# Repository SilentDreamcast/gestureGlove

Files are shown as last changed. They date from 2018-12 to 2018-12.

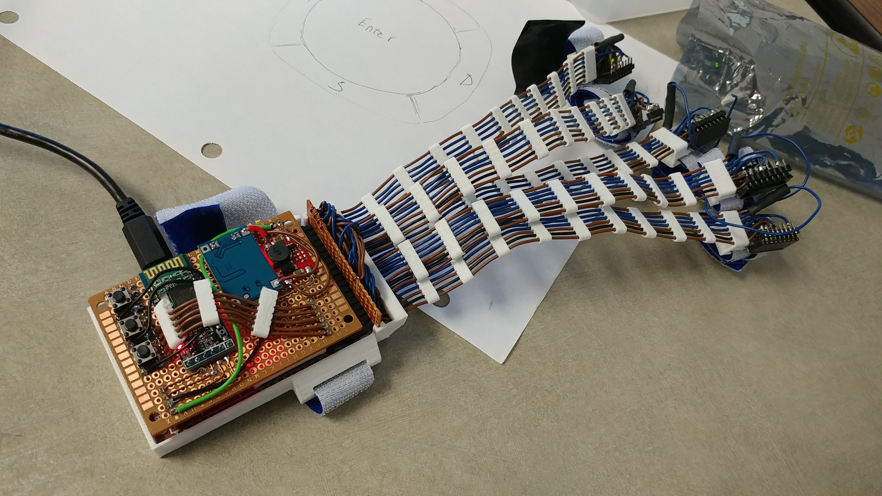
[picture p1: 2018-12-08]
glove.jpg

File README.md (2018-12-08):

# gestureGlove
gestureGlove is a wearable keyboard device that can recognize user hand gestures as a virtual keyboard. The core of the device is the Arduino Leonardo with an ATMEGA32u4 microcontroller.

## Getting Started

These instructions will help you recreate gestureGlove for testing and personal use.
There is a User Manual below.

### Prerequisites
* [Arduino IDE](https://www.arduino.cc/) - you don't have to use this but we did
* [Capacitive Sensing Library](https://playground.arduino.cc/Main/CapacitiveSensor?from=Main.CapSense) 
* [Keyboard Library](https://www.arduino.cc/reference/en/language/functions/usb/keyboard/)
* Arduino Leonardo - or any other board that uses the ATMEGA32u4 microcontroller or similar variant
* Soldering iron, some support components, etc.

### 3D printing
* We included the .stl files modeled in SketchUp to organize the many wires and provide a platform to attach a PCB to.
* These parts are attached to your hand with velcro straps.
* You do not need to print these parts but it makes quality of life and debugging better, especially with a ratsnest of wires and capacitive sensing wires.
* Please look at [glove.jpg] to see how it all comes together.

### Software Setup
```
1. Install the Arduino IDE (available for Windows, Linux, Mac)
2. Install the OLED library directly from within the IDE or git to your *Arduino/libraries* folder.
3. Download the DigiSafe source files
4. Open the .ino file
5. Modify the source to suit your hardware configuration.
6. Plug in your USB device, select the correct COM port and board.
7. Upload the code!
```
## User Manual
* Assemble your device by connecting the base module to the finger sensor array.
* By default the glove is configured for left-hand use. Right-hand use requires swapping the sensor indexes in the source code and reflashing the firmware to the Arduino. In the future, there will be a switch to swap handedness without reprogramming.
* Attach the base module to your wrist with velcro through the mounting points on the 3D printed parts.
* Attach each finger sensor by compressing the touch fabric between the velcro mounting points and finger. Depending on factors such as skin moisture, proximity to electrical noise, etc affects the reading of capacitive sensor. A custom touch threshold may need to be set in the source code and reflashed to the Arduino. In the future, capacitive autocalibration may be added, removing the need for reprogramming.
* After attaching to the hand, connect a USB cable to computer and keep your hand very still for a minute. This time is used for the calibration of the Accelerometer and Gyroscope sensors *notice how led transition time is slow*. Those LEDs represent what finger is currently being read.
* The device is ready for use, currently only supporting 3 buttons on 1 finger.
* Experiment with device...
* Debugging can be accessed by connecting via Bluetooth scannable as BTdebug. This is a serial port that outputs MPU6050 sensor values.
* DEBUGGING: on the base platform, there are 3 buttons.
* DEBUGGING: button 1: toggles debug state (sensor printouts or keyboard engine)
* DEBUGGING: button 2: switches between sensor type: RAW accelerometer, RAW gyroscope, Calibrated Gyroscope Angle with Accelerometer. (sensor printouts)
* DEBUGGING: button 3: switches between sensor axis type: X Y Z, X only, Y only, Z only. (sensor printouts)

## Authors

* **Marvin Mallari** - *Research, Base Hardware Designer, MPU i2c Multiplexer code*, repo-owner
* **Dawei Zhang** - *Research, Capacitive Hardware Designer, Hand Gesture detection code*
* **Kai He** - *Research, Hardware Research, Presentation*

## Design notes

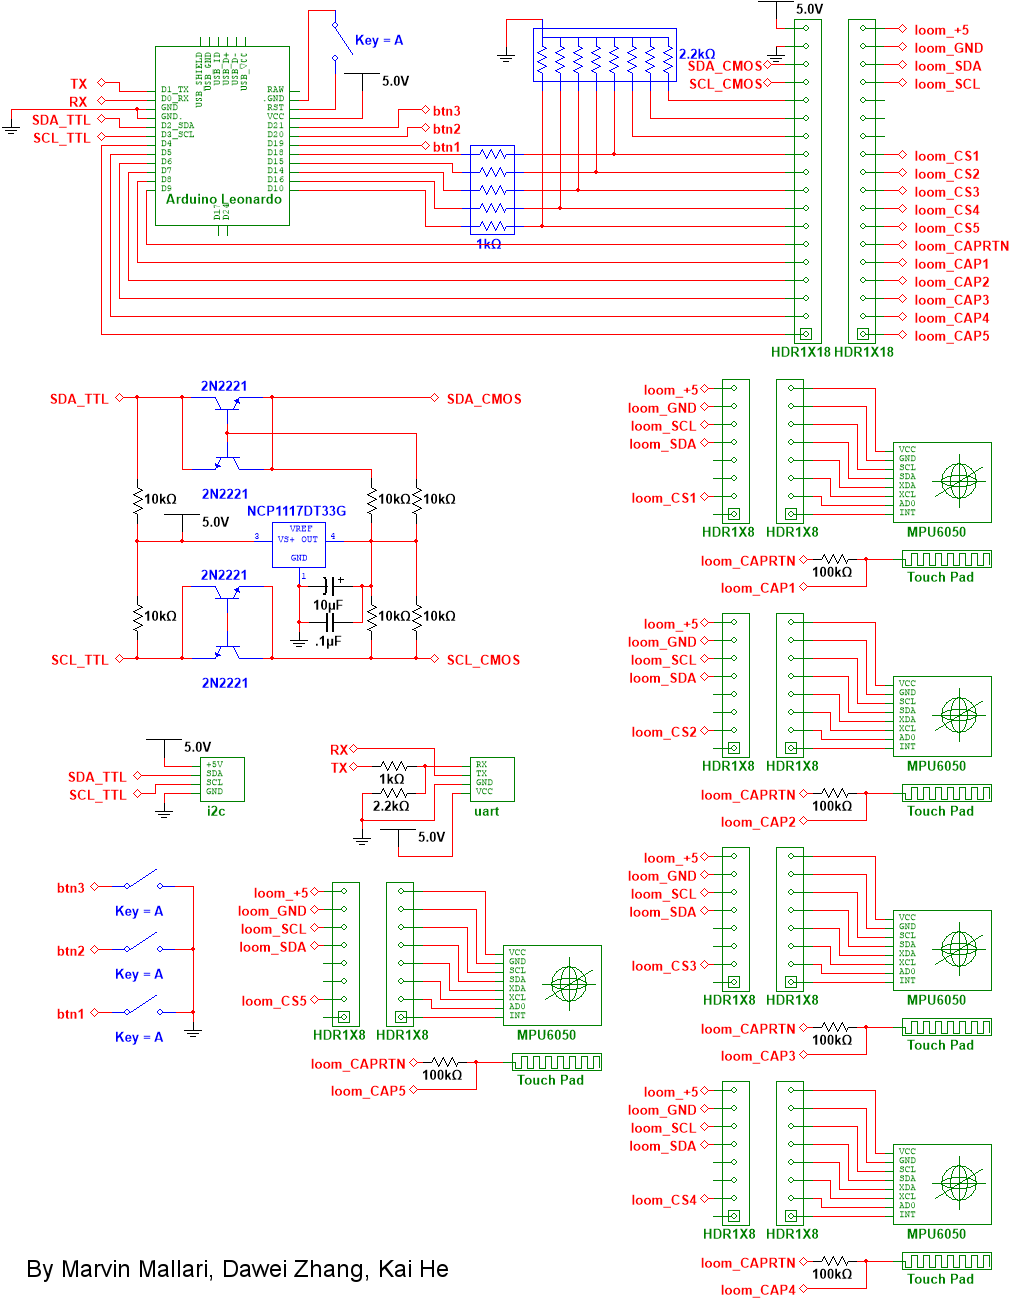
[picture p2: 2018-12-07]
schematic.png

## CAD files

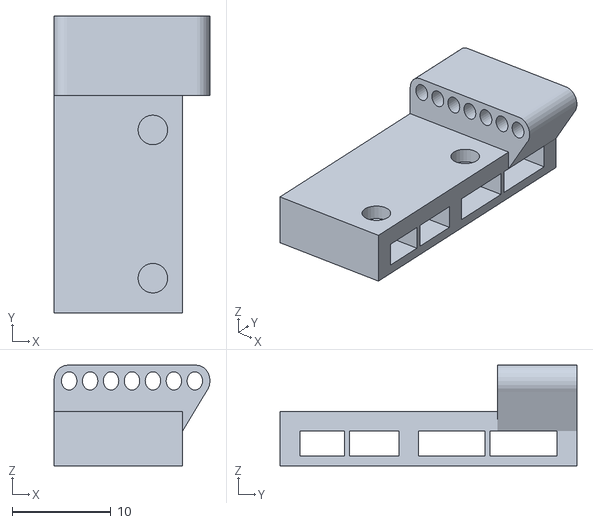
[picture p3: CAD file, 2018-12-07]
3D printable STL/MPU6050holder.stl
15.8 x 30.0 x 10.2

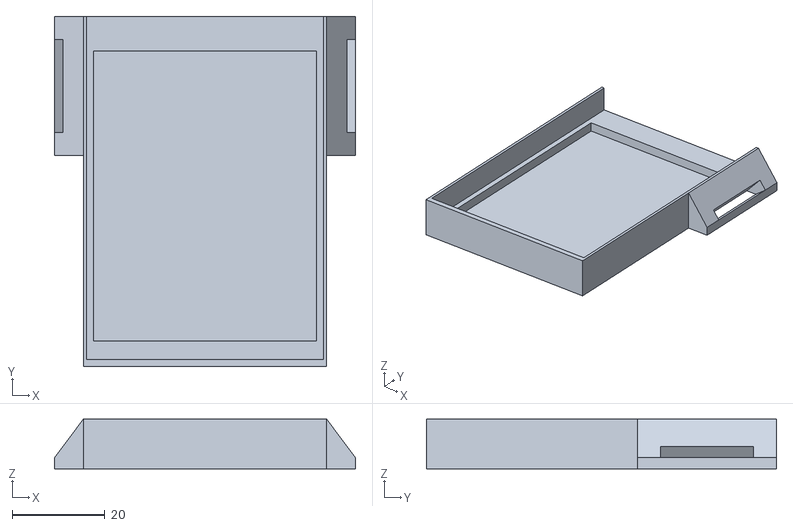
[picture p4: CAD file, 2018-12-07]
3D printable STL/baseHolder.stl
64.9 x 75.5 x 10.7

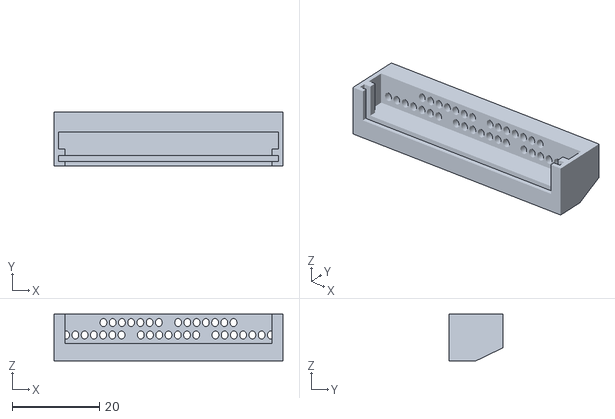
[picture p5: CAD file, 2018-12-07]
3D printable STL/headerComb.stl
52.5 x 12.4 x 10.7

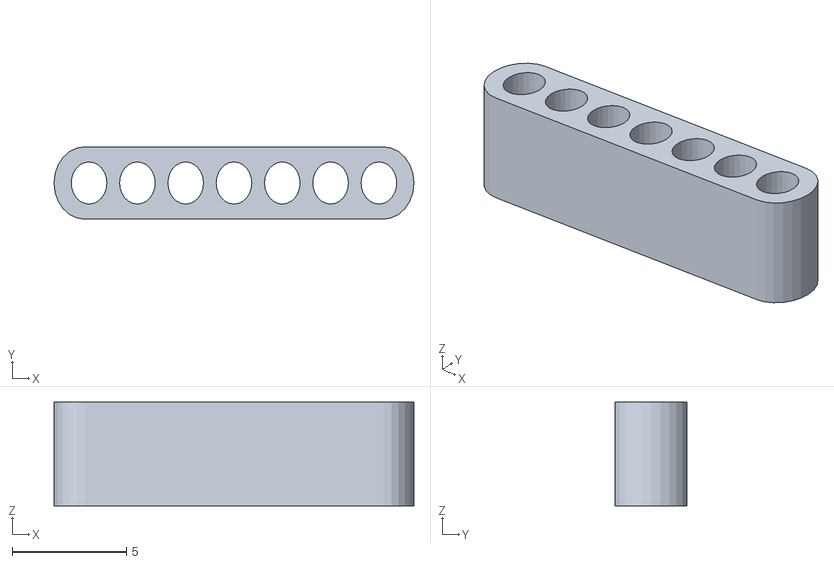
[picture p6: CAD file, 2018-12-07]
3D printable STL/1mmCableComb.stl
15.8 x 3.17 x 4.55

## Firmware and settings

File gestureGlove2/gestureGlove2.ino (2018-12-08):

////////////////////////////////////////////////////////////////////////////////
//                                  Authors                                   //
//----------------------------------------------------------------------------//
// Dawei Zhang                                                                //
// Marvin Anthony Mallari                                                     //
// Kai He                                                                     //
////////////////////////////////////////////////////////////////////////////////
//                                   Rules                                    //
//----------------------------------------------------------------------------//
// Provide github or author for any external libraries                        //
// Dynamic Memory (RAM) is small, use as little as possible                   //
//   -If possible use #define, const, byte, PROGMEM                           //
//   -Avoid int, float, long unless absolutely necessary                      //
// Fast code should not have any Serial.print or must be controllable         //
////////////////////////////////////////////////////////////////////////////////
//                                   Notes                                    //
//----------------------------------------------------------------------------//
// MPU6050 I2C address multiplexing schema: [WORKING 20 October 2018]         //
// * The MPU-6050 supports 2 I2C addresses, 0x68 & 0x69                       //
// * The GY-521 breakout board pulls AD0 low to set address to 0x68           //
// * This address manipulation schema works like Chip Select                  //
// * We will use pins defined in CSpin[] to pull AD0 lines LOW or HIGH        //
// ** Initially all CSpin[]s will be set HIGH 0x69                            //
// ** To read an individual sensor, a single CSpin will be set LOW 0x68       //
// ** Tockn's library will read the sensor based on default address 0x68      //
// ** After reading complete, said pin will be set HIGH 0x69                  //
// ** This repeats until all sensors are read.                                //
//                                                                            //
// MPU6050 drift, limitations, work around [WORK IN PROGRESS]                 //
// * USE DATATYPE ANGLE (calibrated with accelerometer)                       //
// * New schema based on vector guessing avoids sensor drift issue            //
//                                                                            //
// Capacitive Touch schema:                                                   //
// * using vector guessing to figure out position instead of trinonometry math//
// ** this method is good since it is less affected by sensor drift           //




#include "MPU6050_tockn_CUSTOM.h"
#include <Wire.h>
#include "Keyboard.h"
#include <CapacitiveSensor.h>

// define i2c address change pins using Arduino pins A0, D15, D14, D16, D10
const byte CSpin[] = {A0,15,14,16,10};

CapacitiveSensor cs_4_5 = CapacitiveSensor(4,5);
CapacitiveSensor cs_4_6 = CapacitiveSensor(4,6);
CapacitiveSensor cs_4_7 = CapacitiveSensor(4,7);
CapacitiveSensor cs_4_8 = CapacitiveSensor(4,8);
CapacitiveSensor cs_4_9 = CapacitiveSensor(4,9);

//define button pins
#define BTN1 A3
#define BTN2 A2
#define BTN3 A1

// xyz-axis for all fingers
float MPUX[] = {0,0,0,0,0};
float MPUY[] = {0,0,0,0,0};
float MPUZ[] = {0,0,0,0,0};

// xyz-axis as initial
float INITMPUX[] = {0,0,0,0,0};
float INITMPUY[] = {0,0,0,0,0};
float INITMPUZ[] = {0,0,0,0,0};

// initialize MPU6050 objects
MPU6050 MPU0(Wire);
MPU6050 MPU1(Wire);
MPU6050 MPU2(Wire);
MPU6050 MPU3(Wire);
MPU6050 MPU4(Wire);

#define KEY_BACKSPACE 178

// define keyboard 
char Keys[] =   {  KEY_BACKSPACE , 'w' , 's', 'a','d'};
boolean currentPressed[] = { false, false, false, false, false, false };

// Capactive touch threashhold, you might want to mess with this if you find its too
// sensitive or not sensitive enough
#define THRESH 6600

long total1 = 0.0;
long total2 = 0.0;
long total3 = 0.0;
long total4 = 0.0;
long total5 = 0.0;


void setup() {
  //delay(3000);
  Wire.begin(); //start I2C
  Serial1.begin(115200); // set baud-rate on ATMEGA 32u4 secondary UART port.
  // serial bluetooth module needs to be configured to 115200 baud with "AT+BAUD8" (115200), default "AT+BAUD4" (9600)
  cs_4_5.set_CS_AutocaL_Millis(0xFFFFFFFF); // turn off autocalibrate on channel 1 - just as an example for total1
  Serial.begin(115200);
  
  for(byte i = 0; i < 5; i++){
    pinMode(CSpin[i], OUTPUT);
    digitalWrite(CSpin[i], HIGH); // set all MPU6050 addresses to 0x69 by pulling AD0 HIGH, default 0x68 pulled LOW
  }

  pinMode(BTN1, INPUT_PULLUP);
  pinMode(BTN2, INPUT_PULLUP);
  pinMode(BTN3, INPUT_PULLUP);
  
  //i2cScan();
  
  digitalWrite(CSpin[0],LOW);
  delay(10);
  MPU0.begin();
  MPU0.calcGyroOffsets(true);
  digitalWrite(CSpin[0],HIGH);
  digitalWrite(CSpin[1],LOW);
  delay(10);
  MPU1.begin();
  MPU1.calcGyroOffsets(true);
  digitalWrite(CSpin[1],HIGH);
  digitalWrite(CSpin[2],LOW);
  delay(10);
  MPU2.begin();
  MPU2.calcGyroOffsets(true);
  digitalWrite(CSpin[2],HIGH);
  digitalWrite(CSpin[3],LOW);
  delay(10);
  MPU3.begin();
  MPU3.calcGyroOffsets(true);
  digitalWrite(CSpin[3],HIGH);
  digitalWrite(CSpin[4],LOW);
  delay(10);
  MPU4.begin();
  MPU4.calcGyroOffsets(true);
  digitalWrite(CSpin[4],HIGH);
}

boolean reduceMode = false;
byte rMtype = 0;
byte sType = 0;

void loop() {
  updateAll();
  //long start = millis();
  total1 =  cs_4_5.capacitiveSensor(30); // 30 SAMPLES
  total2 =  cs_4_6.capacitiveSensor(30);
  total3 =  cs_4_7.capacitiveSensor(30);
  total4 =  cs_4_8.capacitiveSensor(30);
  total5 =  cs_4_9.capacitiveSensor(30);
  
  if(digitalRead(BTN1) == LOW){ //turn on verbose mode
    delay(250);
    reduceMode = !reduceMode; //toggle
    Serial1.print("DEV MODE: ");
    Serial1.println(reduceMode);
  }
  if(digitalRead(BTN2) == LOW){ //change sensor type
    delay(250);
    sType++;
    if(sType > 4){
      sType = 0;
    }
  }
  if(digitalRead(BTN3) == LOW){ //change axis
    delay(250);
    rMtype++;
    if(rMtype > 3){
      rMtype = 0;
    }
  }
  if(reduceMode){
    if(sType == 0){
      Serial1.print("DATA TYPE: GYRO: ");
      updateGyro();
    }
    if(sType == 1){
      Serial1.print("DATA TYPE: GYRO ANGLE: ");
      updateGyroAngle();
    }
    if(sType == 2){
      Serial1.print("DATA TYPE: ANGLE: ");
      updateAngle();
    }
    if(sType == 3){
      Serial1.print("DATA TYPE: ACCELEROMETER: ");
      updateAccel();
    }
    if(sType == 4){
      Serial1.print("DATA TYPE: TOUCH: ");
      Serial1.print(total1);                  // print sensor output 1
      Serial1.print("\t");
      Serial1.print(total2);                  // print sensor output 2
      Serial1.print("\t");
      Serial1.print(total3);                // print sensor output 3
      Serial1.print("\t");
      Serial1.print(total4);                // print sensor output 3
      Serial1.print("\t");
      Serial1.println(total5);                // print sensor output 3
    }
    
    if(rMtype == 0 && sType != 4) {
      printX();
      printY();
      printZ();
      Serial1.println(); 
    }
    
    else if(rMtype == 1 && sType != 4) {
      printX();
      Serial1.println();
    }
    
    else if(rMtype == 2 && sType != 4) {
      printY();
      Serial1.println();
    }
    
    else if(rMtype == 3 && sType != 4) {
      printZ();
      Serial1.println();
    }
  }
  else{
    keyboardEngine();
  }

  //RUN SHORT RECALIBRATION
  if(digitalRead(BTN1) == LOW && digitalRead(BTN3) == LOW){
    digitalWrite(CSpin[0],LOW);
    delay(10);
    MPU0.quickCalcOffset(true);
    digitalWrite(CSpin[0],HIGH);
    digitalWrite(CSpin[1],LOW);
    delay(10);
    MPU1.quickCalcOffset(true);
    digitalWrite(CSpin[1],HIGH);
    digitalWrite(CSpin[2],LOW);
    delay(10);
    MPU2.quickCalcOffset(true);
    digitalWrite(CSpin[2],HIGH);
    digitalWrite(CSpin[3],LOW);
    delay(10);
    MPU3.quickCalcOffset(true);
    digitalWrite(CSpin[3],HIGH);
    digitalWrite(CSpin[4],LOW);
    delay(10);
    MPU4.quickCalcOffset(true);
    digitalWrite(CSpin[4],HIGH);
  }
}

void printX(){
  Serial1.print("X: ");
  for(byte i = 0; i < 5; i++){
    Serial1.print(MPUX[i]);
    Serial1.print(", ");
  }
}

void printY(){
  Serial1.print("Y: ");
  for(byte i = 0; i < 5; i++){
    Serial1.print(MPUY[i]);
    Serial1.print(", ");
  }
}

void printZ(){
  Serial1.print("Z: ");
  for(byte i = 0; i < 5; i++){
    Serial1.print(MPUZ[i]);
    Serial1.print(", ");
  }
}

// READ ALL SENSORS AND STORE THEM IN THEIR OWN OBJECT MEMORY
void updateAll(){
  digitalWrite(CSpin[0],LOW);
  delay(10);
  MPU0.update();
  digitalWrite(CSpin[0],HIGH);
  delay(10);
  digitalWrite(CSpin[1],LOW);
  delay(10);
  MPU1.update();
  digitalWrite(CSpin[1],HIGH);
  delay(10);
  digitalWrite(CSpin[2],LOW);
  delay(10);
  MPU2.update();
  digitalWrite(CSpin[2],HIGH);
  delay(10);
  digitalWrite(CSpin[3],LOW);
  delay(10);
  MPU3.update();
  digitalWrite(CSpin[3],HIGH);
  delay(10);
  digitalWrite(CSpin[4],LOW);
  delay(10);
  MPU4.update();
  digitalWrite(CSpin[4],HIGH);
}

void updateGyro(){
  MPUX[0] = MPU0.getGyroX();
  MPUX[1] = MPU1.getGyroX();
  MPUX[2] = MPU2.getGyroX();
  MPUX[3] = MPU3.getGyroX();
  MPUX[4] = MPU4.getGyroX();
  
  MPUY[0] = MPU0.getGyroY();
  MPUY[1] = MPU1.getGyroY();
  MPUY[2] = MPU2.getGyroY();
  MPUY[3] = MPU3.getGyroY();
  MPUY[4] = MPU4.getGyroY();
  
  MPUZ[0] = MPU0.getGyroZ();
  MPUZ[1] = MPU1.getGyroZ();
  MPUZ[2] = MPU2.getGyroZ();
  MPUZ[3] = MPU3.getGyroZ();
  MPUZ[4] = MPU4.getGyroZ();
}

void updateGyroAngle(){
  MPUX[0] = MPU0.getGyroAngleX();
  MPUX[1] = MPU1.getGyroAngleX();
  MPUX[2] = MPU2.getGyroAngleX();
  MPUX[3] = MPU3.getGyroAngleX();
  MPUX[4] = MPU4.getGyroAngleX();
  
  MPUY[0] = MPU0.getGyroAngleY();
  MPUY[1] = MPU1.getGyroAngleY();
  MPUY[2] = MPU2.getGyroAngleY();
  MPUY[3] = MPU3.getGyroAngleY();
  MPUY[4] = MPU4.getGyroAngleY();
  
  MPUZ[0] = MPU0.getGyroAngleZ();
  MPUZ[1] = MPU1.getGyroAngleZ();
  MPUZ[2] = MPU2.getGyroAngleZ();
  MPUZ[3] = MPU3.getGyroAngleZ();
  MPUZ[4] = MPU4.getGyroAngleZ();
}

void updateAngle(){
  MPUX[0] = MPU0.getAngleX();
  MPUX[1] = MPU1.getAngleX();
  MPUX[2] = MPU2.getAngleX();
  MPUX[3] = MPU3.getAngleX();
  MPUX[4] = MPU4.getAngleX();
  
  MPUY[0] = MPU0.getAngleY();
  MPUY[1] = MPU1.getAngleY();
  MPUY[2] = MPU2.getAngleY();
  MPUY[3] = MPU3.getAngleY();
  MPUY[4] = MPU4.getAngleY();
  
  MPUZ[0] = MPU0.getAngleZ();
  MPUZ[1] = MPU1.getAngleZ();
  MPUZ[2] = MPU2.getAngleZ();
  MPUZ[3] = MPU3.getAngleZ();
  MPUZ[4] = MPU4.getAngleZ();
}

void updateAccel(){
  MPUX[0] = MPU0.getAccX();
  MPUX[1] = MPU1.getAccX();
  MPUX[2] = MPU2.getAccX();
  MPUX[3] = MPU3.getAccX();
  MPUX[4] = MPU4.getAccX();
  
  MPUY[0] = MPU0.getAccY();
  MPUY[1] = MPU1.getAccY();
  MPUY[2] = MPU2.getAccY();
  MPUY[3] = MPU3.getAccY();
  MPUY[4] = MPU4.getAccY();
  
  MPUZ[0] = MPU0.getAccZ();
  MPUZ[1] = MPU1.getAccZ();
  MPUZ[2] = MPU2.getAccZ();
  MPUZ[3] = MPU3.getAccZ();
  MPUZ[4] = MPU4.getAccZ();
}

//math to do vector guessing
double distanceBetweenTwoPoints(double x, double y, double a, double b){
  return sqrt(pow(x - a, 2) + pow(y - b, 2));
}

void keyboardEngine(){
  //get the orgin
      updateAngle();
       Serial.print("x: ");
       Serial.println(MPUX[0]);
       Serial.print("y: "); 
       Serial.println(MPUY[0]);
       Serial.println(distanceBetweenTwoPoints(MPUX[0],MPUY[0],INITMPUX[0],INITMPUY[0]));
      int keyIndex = 0;
      for (int i = 0; i < 5; i++){ 
        INITMPUX[i] = MPUX[i];
        INITMPUY[i] = MPUY[i];
        INITMPUZ[i] = MPUZ[i];
      }
  // interprets all the data and types the appropriate key
  // check if sensing that a finger is touching the pad
  // and that it wasnt already pressed
   
    if ((total1 > THRESH) && (! currentPressed[0])) { 
      updateAngle();
      if(distanceBetweenTwoPoints(MPUX[0],MPUY[0],INITMPUX[0],INITMPUY[0] )< 10 ){ // Touching is on the middle circle
        keyIndex =0;
        Serial.print("Key pressed #"); 
        Serial.print(keyIndex);
        Serial.print(" ("); 
        Serial.print(Keys[keyIndex]); 
        Serial.println(")");
        currentPressed[keyIndex] = true;
        Keyboard.press( Keys[keyIndex]);
      }
      else{
          if( abs(INITMPUX[0] - MPUX[0]) > abs( INITMPUY[0] - MPUY[0])){ // Detecting the intention of the person's movement
            if( MPUX[0]>0){  // UPPER'w' or LOWER's'
                keyIndex =1;
                Keyboard.press( Keys[1]);
              }
             else{    
                keyIndex =2;
                Keyboard.press( Keys[2]);
              }
          }
          else{
            if( MPUY[0]>0){ // LEFT 'a' or RIGHT 'd'
              keyIndex =3;
              Keyboard.press( Keys[3]);
            }
            else{
              keyIndex =4;
              Keyboard.press( Keys[4]);
            }
          }
      }
    }
    else if ((total1 <= THRESH) && (currentPressed[0])) {
      // key was released (no touch, and it was pressed before)
      Serial.print("Key released #"); 
      Serial.print(0);
      Serial.print(" (");
      Serial.print(Keys[keyIndex]);
      Serial.println(")");
      for (int i = 0; i < 5; i++){ 
        currentPressed[i] = false;
        }
      Keyboard.releaseAll();
    } 
}

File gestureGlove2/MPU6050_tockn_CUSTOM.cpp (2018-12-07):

//original author of this library: Tockn    https://github.com/tockn
//original GitHub library: https://github.com/tockn/MPU6050_tockn
//note: Tockn published to GitHub using MIT License but did not include the below statement so we are including it in our redistribution.

/*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
 * The above copyright notice and this permission notice shall be included in all copies or substantial portions of the Software.
 * 
 * THE SOFTWARE IS PROVIDED "AS IS", WITHOUT WARRANTY OF ANY KIND, EXPRESS OR IMPLIED, INCLUDING BUT NOT LIMITED TO THE WARRANTIES OF MERCHANTABILITY, FITNESS FOR A PARTICULAR PURPOSE AND NONINFRINGEMENT. IN NO EVENT SHALL THE AUTHORS OR COPYRIGHT HOLDERS BE LIABLE FOR ANY CLAIM, DAMAGES OR OTHER LIABILITY, WHETHER IN AN ACTION OF CONTRACT, TORT OR OTHERWISE, ARISING FROM, OUT OF OR IN CONNECTION WITH THE SOFTWARE OR THE USE OR OTHER DEALINGS IN THE SOFTWARE.
 */

#include "MPU6050_tockn_CUSTOM.h"
#include "Arduino.h"

MPU6050::MPU6050(TwoWire &w){
	wire = &w;
	accCoef = 0.02f;
	gyroCoef = 0.98f;
}

MPU6050::MPU6050(TwoWire &w, float aC, float gC){
	wire = &w;
	accCoef = aC;
	gyroCoef = gC;
}

void MPU6050::begin(){
	writeMPU6050(MPU6050_SMPLRT_DIV, 0x00);
	writeMPU6050(MPU6050_CONFIG, 0x00);
	writeMPU6050(MPU6050_GYRO_CONFIG, 0x08);
	writeMPU6050(MPU6050_ACCEL_CONFIG, 0x00);
	writeMPU6050(MPU6050_PWR_MGMT_1, 0x01);
	this->update();
	angleGyroX = 0;
	angleGyroY = 0;
  angleX = this->getAccAngleX();
  angleY = this->getAccAngleY();
  preInterval = millis();
}

void MPU6050::writeMPU6050(byte reg, byte data){
	wire->beginTransmission(MPU6050_ADDR);
	wire->write(reg);
	wire->write(data);
	wire->endTransmission();
}

byte MPU6050::readMPU6050(byte reg) {
	wire->beginTransmission(MPU6050_ADDR);
	wire->write(reg);
	wire->endTransmission(true);
	wire->requestFrom((uint8_t)MPU6050_ADDR, (size_t)2/*length*/);
	byte data =  wire->read();
	wire->read();
	return data;
}

void MPU6050::setGyroOffsets(float x, float y, float z){
	gyroXoffset = x;
	gyroYoffset = y;
	gyroZoffset = z;
}

void MPU6050::calcGyroOffsets(bool console){
	float x = 0, y = 0, z = 0;
	int16_t rx, ry, rz;

  delay(1000);
	if(console){
    Serial1.println();
    Serial1.println("========================================");
		Serial1.println("calculating gyro offsets");
		Serial1.print("DO NOT MOVE");
	}
	for(int i = 0; i < 3000; i++){
		if(console && i % 100 == 0){
			Serial1.print(".");
		}
		wire->beginTransmission(MPU6050_ADDR);
		wire->write(0x3B);
		wire->endTransmission(false);
		wire->requestFrom((int)MPU6050_ADDR, 14, (int)true);

		wire->read() << 8 | wire->read();
		wire->read() << 8 | wire->read();
		wire->read() << 8 | wire->read();
		wire->read() << 8 | wire->read();
		rx = wire->read() << 8 | wire->read();
		ry = wire->read() << 8 | wire->read();
		rz = wire->read() << 8 | wire->read();

		x += ((float)rx) / 65.5;
		y += ((float)ry) / 65.5;
		z += ((float)rz) / 65.5;
	}
	gyroXoffset = x / 3000;
	gyroYoffset = y / 3000;
	gyroZoffset = z / 3000;

	if(console){
    Serial1.println();
		Serial1.println("Done!!!");
		Serial1.print("X : ");Serial1.println(gyroXoffset);
		Serial1.print("Y : ");Serial1.println(gyroYoffset);
		Serial1.print("Z : ");Serial1.println(gyroZoffset);
    Serial1.println("========================================");
		delay(500);
	}
}
void MPU6050::quickCalcOffset(bool console){
  float x = 0, y = 0, z = 0;
  int16_t rx, ry, rz;

  if(console){
    Serial1.println();
    Serial1.println("QUICK CALIBRATION: DO NOT MOVE");
  }
  for(int i = 0; i < 1000; i++){
    if(console && i % 100 == 0){
      Serial1.print(".");
    }
    wire->beginTransmission(MPU6050_ADDR);
    wire->write(0x3B);
    wire->endTransmission(false);
    wire->requestFrom((int)MPU6050_ADDR, 14, (int)true);

    wire->read() << 8 | wire->read();
    wire->read() << 8 | wire->read();
    wire->read() << 8 | wire->read();
    wire->read() << 8 | wire->read();
    rx = wire->read() << 8 | wire->read();
    ry = wire->read() << 8 | wire->read();
    rz = wire->read() << 8 | wire->read();

    x += ((float)rx) / 65.5;
    y += ((float)ry) / 65.5;
    z += ((float)rz) / 65.5;
  }
  gyroXoffset = x / 1000;
  gyroYoffset = y / 1000;
  gyroZoffset = z / 1000;

  if(console){
    Serial1.print("NEW OFFSET: ");
    Serial1.print("X : ");Serial1.print(gyroXoffset);
    Serial1.print("  Y : ");Serial1.print(gyroYoffset);
    Serial1.print("  Z : ");Serial1.println(gyroZoffset);
  }
}

void MPU6050::update(){
	wire->beginTransmission(MPU6050_ADDR);
	wire->write(0x3B);
	wire->endTransmission(false);
	wire->requestFrom((int)MPU6050_ADDR, 14, (int)true);

	rawAccX = wire->read() << 8 | wire->read();
	rawAccY = wire->read() << 8 | wire->read();
	rawAccZ = wire->read() << 8 | wire->read();
	rawTemp = wire->read() << 8 | wire->read();
	rawGyroX = wire->read() << 8 | wire->read();
	rawGyroY = wire->read() << 8 | wire->read();
	rawGyroZ = wire->read() << 8 | wire->read();

	temp = (rawTemp + 12412.0) / 340.0;

	accX = ((float)rawAccX) / 16384.0;
	accY = ((float)rawAccY) / 16384.0;
	accZ = ((float)rawAccZ) / 16384.0;

	angleAccX = atan2(accY, accZ + abs(accX)) * 360 / 2.0 / PI;
	angleAccY = atan2(accX, accZ + abs(accY)) * 360 / -2.0 / PI;

	gyroX = ((float)rawGyroX) / 65.5;
	gyroY = ((float)rawGyroY) / 65.5;
	gyroZ = ((float)rawGyroZ) / 65.5;

	gyroX -= gyroXoffset;
	gyroY -= gyroYoffset;
	gyroZ -= gyroZoffset;

	interval = (millis() - preInterval) * 0.001;

	angleGyroX += gyroX * interval;
	angleGyroY += gyroY * interval;
	angleGyroZ += gyroZ * interval;

	angleX = (gyroCoef * (angleX + gyroX * interval)) + (accCoef * angleAccX);
	angleY = (gyroCoef * (angleY + gyroY * interval)) + (accCoef * angleAccY);
	angleZ = angleGyroZ;

	preInterval = millis();

}

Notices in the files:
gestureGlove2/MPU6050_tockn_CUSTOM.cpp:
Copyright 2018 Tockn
